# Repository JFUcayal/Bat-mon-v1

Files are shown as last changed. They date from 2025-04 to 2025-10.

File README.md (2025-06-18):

# Bat-mon-v1
**Edge Device for Battery Environment Monitoring System (Lithium Storage and Transport)**

- **Bat-Mon** is a hardware/firmware project developed as part of my Master's thesis in an industrial environment at [b.again](https://b.again.pt/pt_PT/) [(dstgroup)](https://www.dstsgps.com/intro-pt-pt/#/#intro), focused on the real-time monitoring of lithium batteries. 
- It includes custom-designed PCBs for fixed and portable use cases, enabling the detection of environmental conditions such as **temperature**, **humidity**, and **vibration**. All hardware was developed using **KiCAD**.
- This project was developed in the context of a national R&D consortium for advanced energy storage systems:  
[New Generation Storage](https://newgenstorage.pt). It is partially funded by the **PRR – Recovery and Resilience Plan** and aims to support innovation in battery safety and smart monitoring systems.

## 🔧 Project Overview

Lithium batteries, whether in stationary storage or during transport, require careful environmental monitoring to ensure safety. Bat-Mon addresses this need by providing two types of monitoring devices:

- **Stationary Unit**: Designed for static storage. Measures temperature and humidity.
- **Portable Unit**: Designed for battery transport scenarios. Measures temperature, humidity, and vibration.

Both units support low-power operation and are intended to be integrated into broader telemetry or management systems.

## 📟 3D Views of the PCBs
<div id="image-table" align="center">
    <table>
        <tr>
            <td style="padding:10px"> <strong>📦 Stationary Monitoring Prototype</strong><br/><br/>
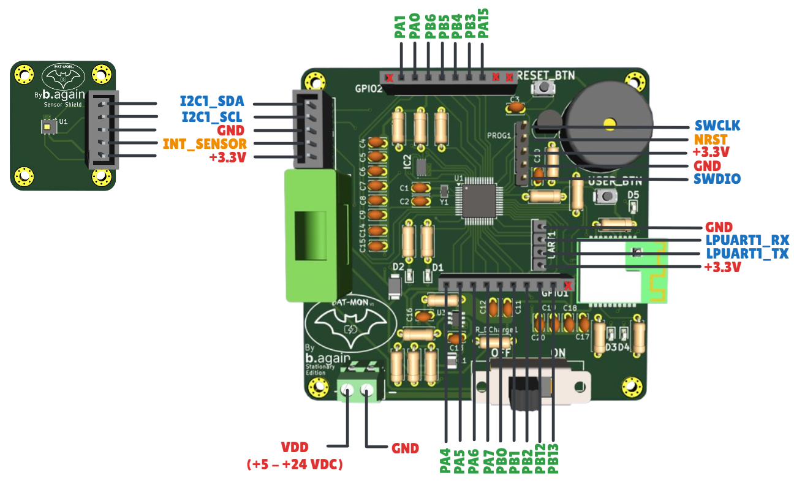
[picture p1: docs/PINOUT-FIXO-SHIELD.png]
Stationary Prototype 3D View
                
            </td>
            <td style="padding:10px"> <br/><strong>🚚 Portable Monitoring Prototype</strong><br/><br/>
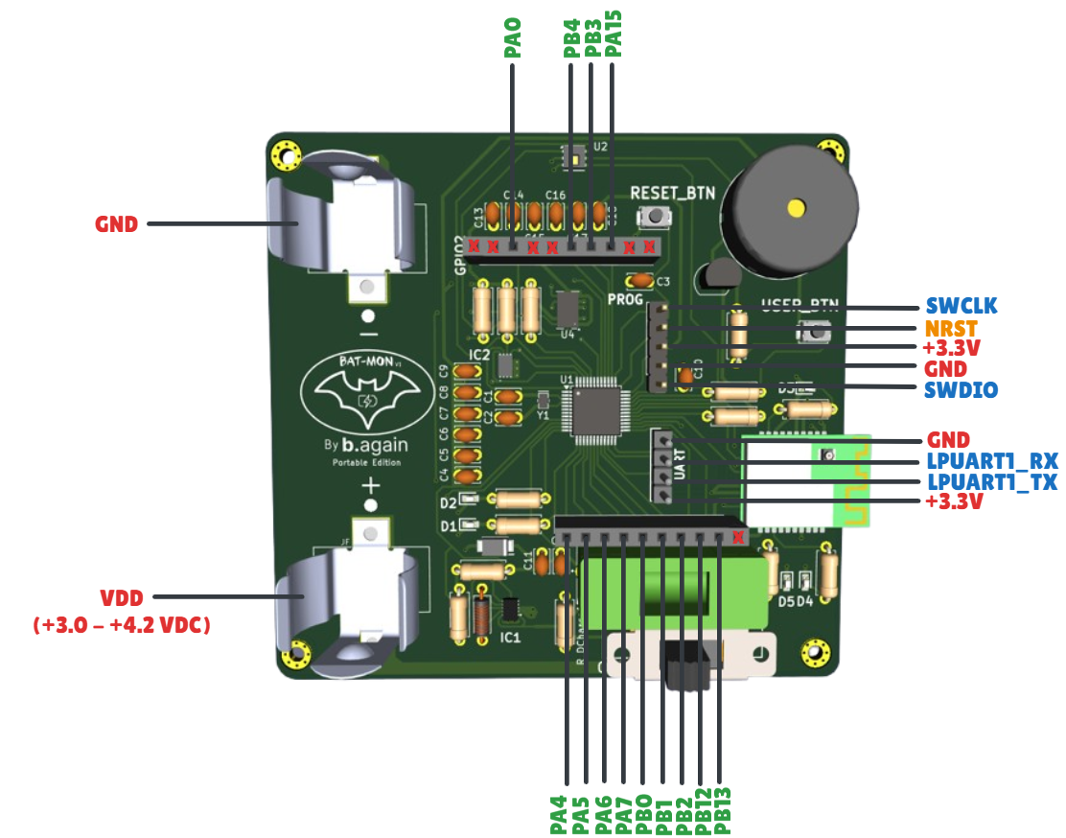
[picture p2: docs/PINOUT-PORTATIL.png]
Portable Prototype 3D View
                 
            </td>
        </tr>
    </table>
</div>
    
## 🚀 Key Features

- 🌡️ **Temperature and Humidity Sensing**
- 📈 **Vibration Detection** (portable unit)
- 📶 **BLE Communication Support**
- 🔋 **Low Power Design**
- 📐 **Designed in KiCAD**
- 🧠 **Powered by STM32**

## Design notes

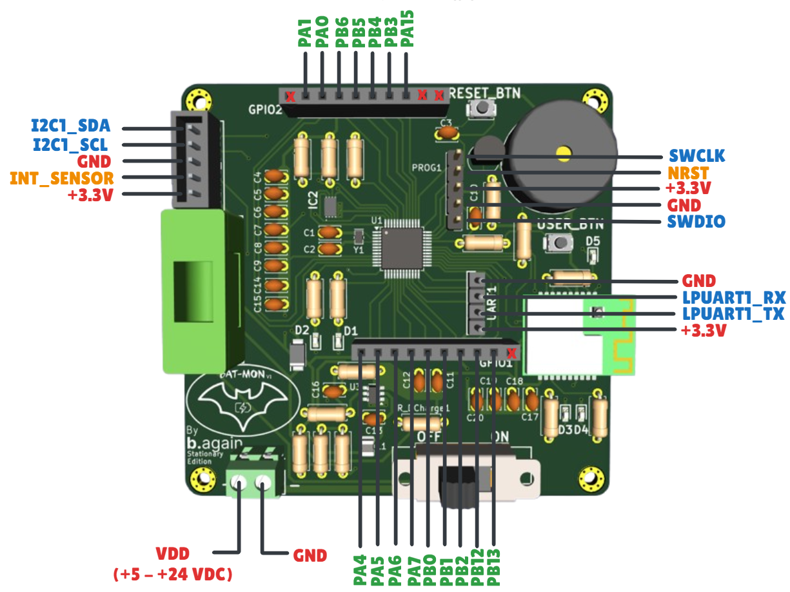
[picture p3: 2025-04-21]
docs/PINOUT-FIXO.png

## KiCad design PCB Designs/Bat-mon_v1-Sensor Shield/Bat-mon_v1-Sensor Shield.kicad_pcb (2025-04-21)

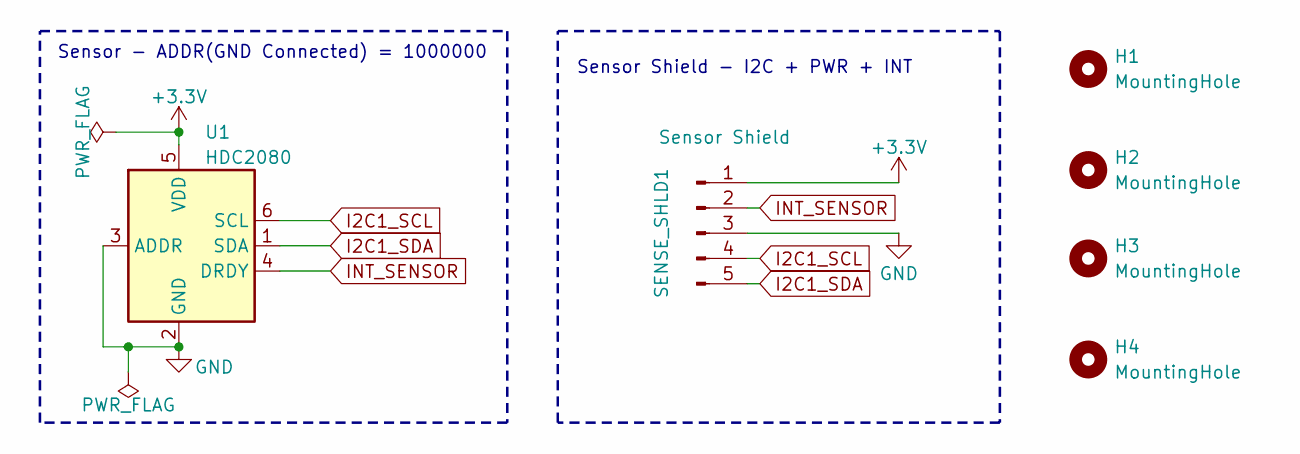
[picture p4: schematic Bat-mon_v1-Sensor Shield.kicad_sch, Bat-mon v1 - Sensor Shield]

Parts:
H1, H2, H3, H4: MountingHole; MountingHole_2.2mm_M2_Pad_Via
SENSE_SHLD1: Sensor Shield; SHDR5W64P0X250_1X5_1490X575X700P
U1: HDC2080; Texas_PWSON-N6

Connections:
+3.3V: SENSE_SHLD1.1, U1.5 (VDD)
GND: SENSE_SHLD1.3, U1.2 (GND), U1.3 (ADDR)
I2C1_SCL: SENSE_SHLD1.4, U1.6 (SCL)
I2C1_SDA: SENSE_SHLD1.5, U1.1 (SDA)
INT_SENSOR: SENSE_SHLD1.2, U1.4 (DRDY)

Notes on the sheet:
Sensor - ADDR(GND Connected) = 1000000
Sensor Shield - I2C + PWR + INT

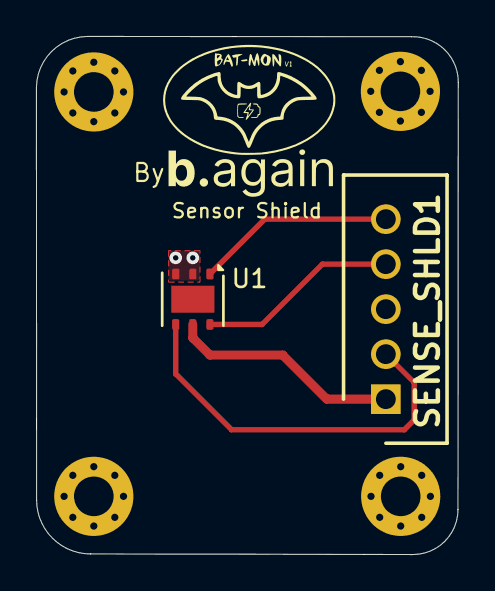
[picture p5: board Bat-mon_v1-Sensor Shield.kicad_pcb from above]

Board: 2 copper layers, 23.4 x 28.8 mm, 6 parts (0 on the bottom side), 5 nets.

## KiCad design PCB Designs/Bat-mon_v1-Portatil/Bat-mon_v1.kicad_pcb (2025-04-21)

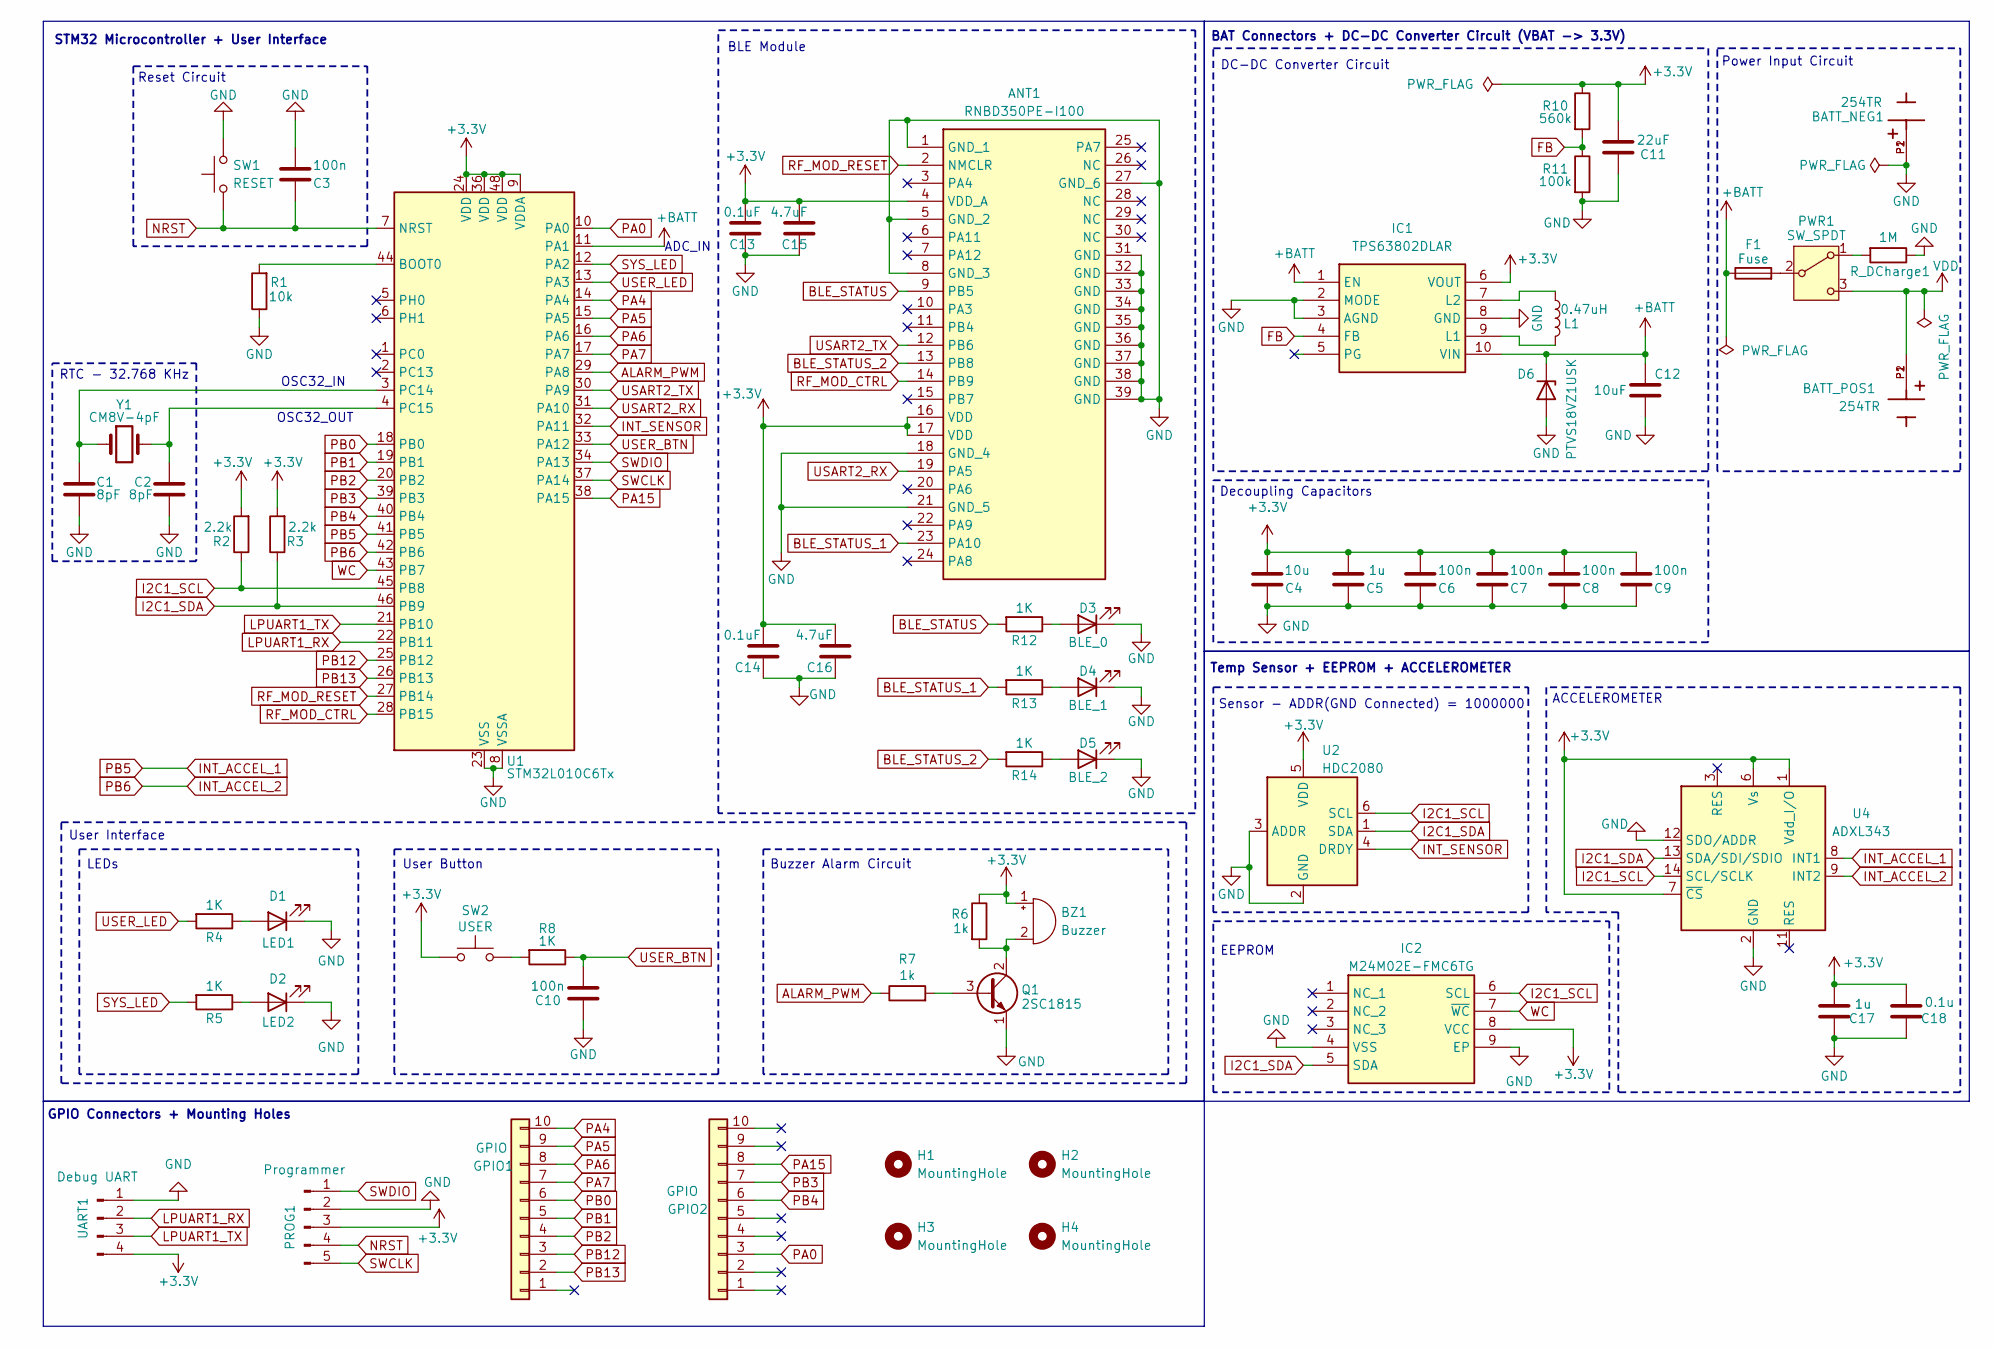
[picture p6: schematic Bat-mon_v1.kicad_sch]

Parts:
ANT1: RNBD350PE-I100; RNBD350PE-I100 - BLE Module; Manufacturer_Part_Number RNBD451PE-I100; Mouser Part Number 579-RNBD451PE-I100
BATT_NEG1: 254TR; BAT_254TR; PARTREV C
BATT_POS1: 254TR; BAT_254TR; PARTREV C
BZ1: Buzzer; PS17_1
C1, C2: 8pF; C_Disc_D3.4mm_W2.1mm_P2.50mm
C3, C6, C7, C8, C9, C10: 100n; C_Disc_D3.4mm_W2.1mm_P2.50mm
C4: 10u; C_Disc_D3.4mm_W2.1mm_P2.50mm
C5, C17: 1u; C_Disc_D3.4mm_W2.1mm_P2.50mm
C11: 22uF; C_Disc_D3.4mm_W2.1mm_P2.50mm
C12: 10uF; C_Disc_D3.4mm_W2.1mm_P2.50mm
C13, C14: 0.1uF; C_Disc_D3.4mm_W2.1mm_P2.50mm
C15, C16: 4.7uF; C_Disc_D3.4mm_W2.1mm_P2.50mm
C18: 0.1u; C_Disc_D3.4mm_W2.1mm_P2.50mm
D1: LED1; LEDC1608X80N
D2: LED2; LEDC1608X80N
D3: BLE_0; LEDC1608X80N
D4: BLE_1; LEDC1608X80N
D5: BLE_2; LEDC1608X80N
D6: PTVS18VZ1USK; SODFL4725X105N
F1: Fuse; WR-FSH_THT_2
GPIO1, GPIO2: GPIO; Header_F_1X10_61301011821
H1, H2, H3, H4: MountingHole; MountingHole_2.2mm_M2_Pad_Via
IC1: TPS63802DLAR; Mouser Part Number 595-TPS63802DLAR
IC2: M24M02E-FMC6TG; M24M02EFMC6TG; Mouser Part Number 511-M24M02E-FMC6TG
L1: 0.47uH; L_Axial_L5.3mm_D2.2mm_P7.62mm_Horizontal_Vishay_IM-1
PROG1: Programmer; PinHeader_1x05_P2.54mm_Vertical
PWR1: SW_SPDT; SLW2327758AND
Q1: 2SC1815; TO-92_Inline
R1: 10k; R_Axial_DIN0207_L6.3mm_D2.5mm_P7.62mm_Horizontal
R2, R3: 2.2k; R_Axial_DIN0207_L6.3mm_D2.5mm_P7.62mm_Horizontal
R4, R5, R8, R12, R13, R14: 1K; R_Axial_DIN0207_L6.3mm_D2.5mm_P7.62mm_Horizontal
R6, R7: 1k; R_Axial_DIN0207_L6.3mm_D2.5mm_P7.62mm_Horizontal
R10: 560k; R_Axial_DIN0207_L6.3mm_D2.5mm_P7.62mm_Horizontal
R11: 100k; R_Axial_DIN0207_L6.3mm_D2.5mm_P7.62mm_Horizontal
R_DCharge1: 1M; R_Axial_DIN0207_L6.3mm_D2.5mm_P7.62mm_Horizontal
SW1: RESET; SW_Push_SPST_NO_Alps_SKRK
SW2: USER; SW_Push_SPST_NO_Alps_SKRK
U1: STM32L010C6Tx; LQFP-48_7x7mm_P0.5mm
U2: HDC2080; Texas_PWSON-N6
U4: ADXL343; LGA-14_3x5mm_P0.8mm_LayoutBorder1x6y
UART1: Debug UART; Header_M_1X4_61300411121
Y1: CM8V-4pF; Crystal_SMD_MicroCrystal_CC8V-T1A-2Pin_2.0x1.2mm

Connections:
+3.3V: ANT1.4 (VDD_A), ANT1.16 (VDD), ANT1.17 (VDD), BZ1.1 (+), C4.2, C5.2, C6.2, C7.2, C8.2, C9.2, C11.2, C13.2, C14.2, C15.2, C16.2, C17.2, C18.2, IC1.6 (VOUT), IC2.8 (VCC), PROG1.3, R2.2, R3.2, R6.1, R10.1, SW2.1, U1.9 (VDDA), U1.24 (VDD), U1.36 (VDD), U1.48 (VDD), U2.5 (VDD), U4.1 (Vdd_I/O), U4.6 (Vs), U4.7 (~CS), UART1.4
+BATT: C12.2, D6.1 (K), F1.1, IC1.1 (EN), IC1.10 (VIN), U1.11 (PA1)
ALARM_PWM: R7.1, U1.29 (PA8)
BLE_STATUS: ANT1.9 (PB5), R12.2
BLE_STATUS_1: ANT1.23 (PA10), R13.2
BLE_STATUS_2: ANT1.13 (PB8), R14.2
FB: IC1.4 (FB), R10.2, R11.1
GND: ANT1.1 (GND_1), ANT1.5 (GND_2), ANT1.8 (GND_3), ANT1.18 (GND_4), ANT1.21 (GND_5), ANT1.27 (GND_6), ANT1.31 (GND), ANT1.32 (GND), ANT1.33 (GND), ANT1.34 (GND), ANT1.35 (GND), ANT1.36 (GND), ANT1.37 (GND), ANT1.38 (GND), ANT1.39 (GND), BATT_NEG1.P1, BATT_NEG1.P2, C1.2, C2.2, C3.2, C4.1, C5.1, C6.1, C7.1, C8.1, C9.1, C10.1, C11.1, C12.1, C13.1, C14.1, C15.1, C16.1, C17.1, C18.1, D1.1 (K), D2.1 (K), D3.1 (K), D4.1 (K), D5.1 (K), D6.2 (A), IC1.2 (MODE), IC1.3 (AGND), IC1.8 (GND), IC2.4 (VSS), IC2.9 (EP), PROG1.2, Q1.1 (E), R1.1, R11.2, R_DCharge1.1, SW1.2, U1.8 (VSSA), U1.23 (VSS), U1.35 (VSS), U1.47 (VSS), U2.2 (GND), U2.3 (ADDR), U4.2 (GND), U4.4 (GND), U4.5 (GND), U4.12 (SDO/ADDR), UART1.1
I2C1_SCL: IC2.6 (SCL), R2.1, U1.45 (PB8), U2.6 (SCL), U4.14 (SCL/SCLK)
I2C1_SDA: IC2.5 (SDA), R3.1, U1.46 (PB9), U2.1 (SDA), U4.13 (SDA/SDI/SDIO)
INT_ACCEL_1: U1.41 (PB5), U4.8 (INT1)
INT_ACCEL_2: U1.42 (PB6), U4.9 (INT2)
INT_SENSOR: U1.32 (PA11), U2.4 (DRDY)
LPUART1_RX: U1.22 (PB11), UART1.2
LPUART1_TX: U1.21 (PB10), UART1.3
NRST: C3.1, PROG1.4, SW1.1, U1.7 (NRST)
unnamed: BZ1.2 (-), Q1.2 (C), R6.2
unnamed: D1.2 (A), R4.1
unnamed: D2.2 (A), R5.1
unnamed: D3.2 (A), R12.1
unnamed: D4.2 (A), R13.1
unnamed: D5.2 (A), R14.1
unnamed: IC1.9 (L1), L1.2
unnamed: IC1.7 (L2), L1.1
unnamed: PWR1.1 (A), R_DCharge1.2
unnamed: F1.2, PWR1.2 (B)
unnamed: Q1.3 (B), R7.2
unnamed: R8.2, SW2.2
unnamed: R1.2, U1.44 (BOOT0)
unnamed: C1.1, U1.3 (PC14), Y1.1
unnamed: C2.1, U1.4 (PC15), Y1.2
PA0: GPIO2.3, U1.10 (PA0)
PA4: GPIO1.10, U1.14 (PA4)
PA5: GPIO1.9, U1.15 (PA5)
PA6: GPIO1.8, U1.16 (PA6)
PA7: GPIO1.7, U1.17 (PA7)
PA15: GPIO2.8, U1.38 (PA15)
PB0: GPIO1.6, U1.18 (PB0)
PB1: GPIO1.5, U1.19 (PB1)
PB2: GPIO1.4, U1.20 (PB2)
PB3: GPIO2.7, U1.39 (PB3)
PB4: GPIO2.6, U1.40 (PB4)
PB12: GPIO1.3, U1.25 (PB12)
PB13: GPIO1.2, U1.26 (PB13)
RF_MOD_CTRL: ANT1.14 (PB9), U1.28 (PB15)
RF_MOD_RESET: ANT1.2 (NMCLR), U1.27 (PB14)
SWCLK: PROG1.5, U1.37 (PA14)
SWDIO: PROG1.1, U1.34 (PA13)
SYS_LED: R5.2, U1.12 (PA2)
USART2_RX: ANT1.19 (PA5), U1.31 (PA10)
USART2_TX: ANT1.12 (PB6), U1.30 (PA9)
USER_BTN: C10.2, R8.1, U1.33 (PA12)
USER_LED: R4.2, U1.13 (PA3)
VDD: BATT_POS1.P1, BATT_POS1.P2, PWR1.3 (C)
WC: IC2.7 (~WC), U1.43 (PB7)

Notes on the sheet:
EEPROM
GPIO Connectors + Mounting Holes
BLE Module
User Button
RTC - 32.768 KHz
User Interface
LEDs
BAT Connectors + DC-DC Converter Circuit (VBAT -> 3.3V)
Sensor - ADDR(GND Connected) = 1000000
DC-DC Converter Circuit
STM32 Microcontroller + User Interface
OSC32_IN
Temp Sensor + EEPROM + ACCELEROMETER
OSC32_OUT
ADC_IN
Buzzer Alarm Circuit
Decoupling Capacitors
Power Input Circuit
ACCELEROMETER
Reset Circuit

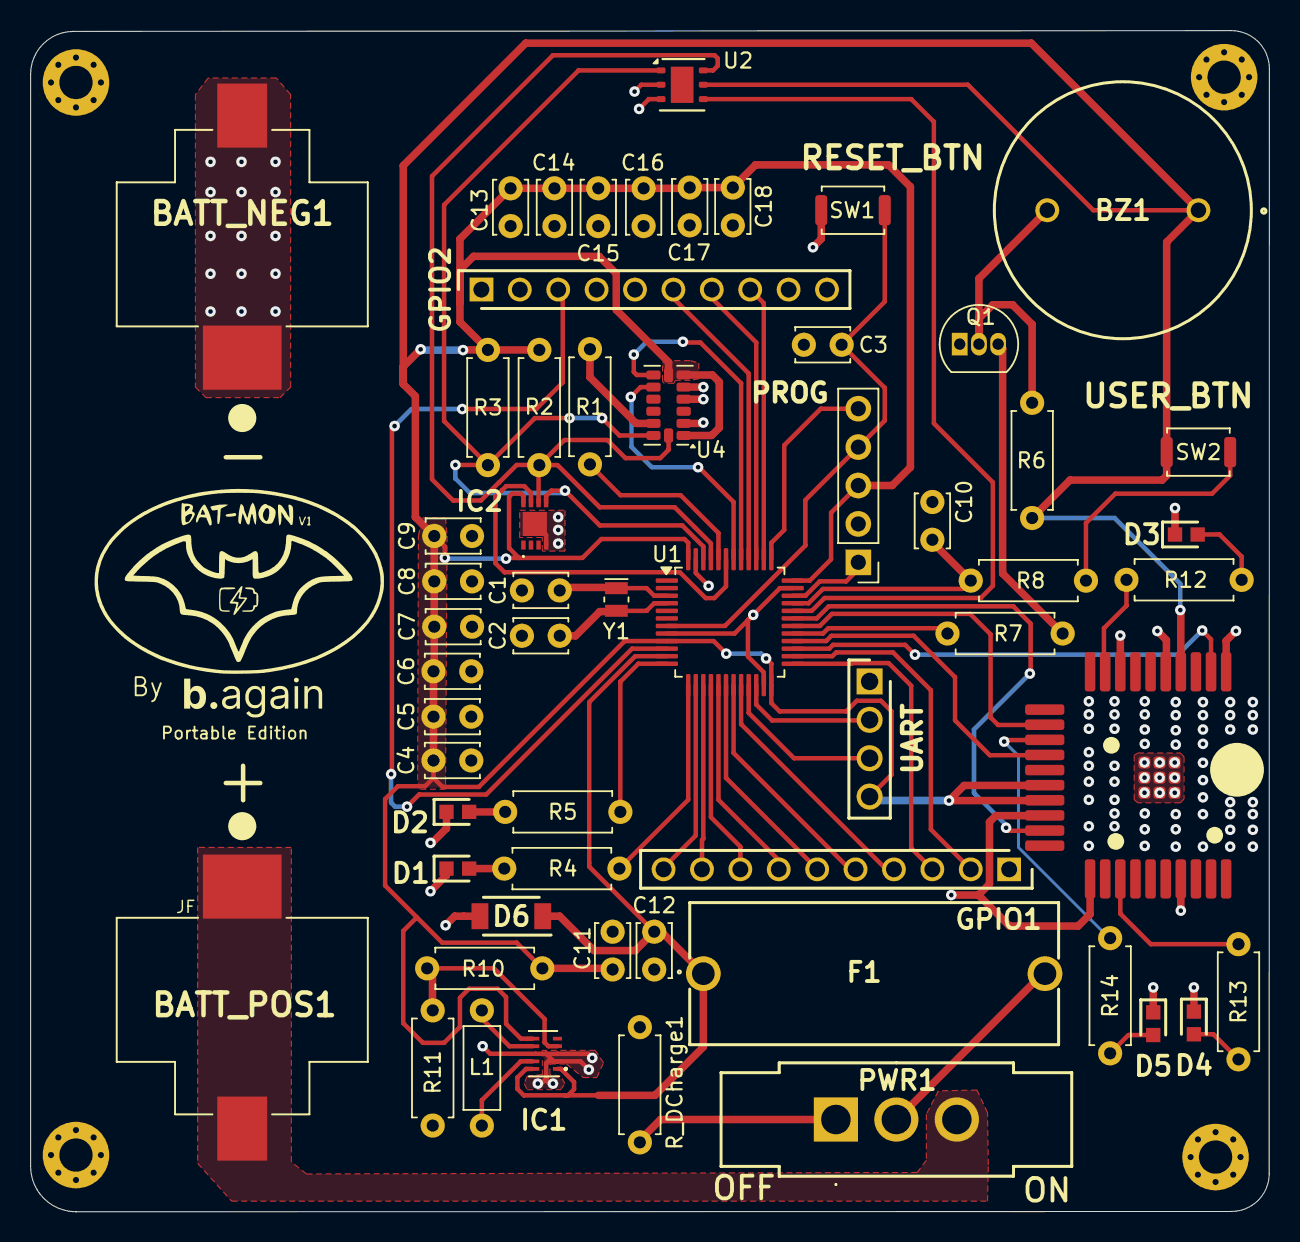
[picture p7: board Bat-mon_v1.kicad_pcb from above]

Board: 2 copper layers, 81.9 x 78.1 mm, 62 parts (0 on the bottom side), 55 nets.

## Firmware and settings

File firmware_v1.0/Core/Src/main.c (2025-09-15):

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
/* Includes ------------------------------------------------------------------*/
#include "main.h"
#include "i2c.h"
#include "usart.h"
#include "rtc.h"
#include "tim.h"
#include "gpio.h"

/* USER CODE BEGIN Includes */
#include <stdio.h>
#include "app.h"
/* USER CODE END Includes */


/* USER CODE BEGIN PV */
uint8_t volatile button_counter = 0;
uint32_t current_millisecs = 0, last_debounce_time = 0;
bool flag_timer_on = false;
extern enum states NEXT_STATE;
/* USER CODE END PV */

void SystemClock_Config(void);
/* USER CODE BEGIN 0 */

void HAL_GPIO_EXTI_Callback(uint16_t GPIO_Pin){

	// Check USER BUTTON click number (Manual Mode)
	if(GPIO_Pin == USER_BTN){


		// blink sys LED
		//HAL_GPIO_TogglePin(GPIOA, SYS_LED_PIN);


		//Debounce
		current_millisecs = HAL_GetTick();
		if(current_millisecs >= 0xFFFFFFF0){
			current_millisecs  = 0;
			last_debounce_time = 0;
		}

		// Check condition for debounce time
		if(current_millisecs - last_debounce_time >= DEBOUNCE_DELAY){

			//log_write(WARNING_LOG, "INT BUTTON ");

			if(!flag_timer_on){
				flag_timer_on = true;
				// stop_timer -> stop time trigger and start counting button time trigger
				start_timer_INT(BUTTON_TIMER);
			}
			button_counter++;
		}
		//For checking the difference between this interrupt and the upcoming INT
		last_debounce_time = current_millisecs;


		// blink sys LED
		//HAL_GPIO_TogglePin(GPIOA, SYS_LED_PIN);
	}

	// Check T+H Sensor INT source
	if(GPIO_Pin == INT_HDC2080_PIN){

		//TODO: Testing purpose only
		//log_write(WARNING_LOG, "INT SENSOR GENERATED");

		// Disable T+H Sensor INT -> Re-Enable in IDLE State -> 5 PULSES GENERATED IN EACH INTERRUPT -> clear flag after first INT

		// Check Thresholds bits (Temp High || Hum High)
		if(check_threshold_active()){
			NEXT_STATE = ANOMALY;
		} else {
			NEXT_STATE = IDLE;
		}
	}
}

// TIMER CALLBACK
// De 1 em 1 segundos checkar o valor do button counter e apos avaliar fazer reset
void HAL_TIM_PeriodElapsedCallback(TIM_HandleTypeDef *htim){

	if(htim == BUTTON_TIMER){

		// verificar se flag_button_INT ou flag_time_trigger_INT (sampling time)	TODO: ADD functionality

		flag_timer_on = false;
		stop_timer(BUTTON_TIMER);

		//log_write(WARNING_LOG, "INT time - %u", button_counter);

		switch(button_counter){
			case 1:
				NEXT_STATE = DATA_READ;
				break;
			case 2:
				NEXT_STATE = LOGS;
				break;
			case 3:
				NEXT_STATE = RECONNECT;
				break;
			case 5:
				NEXT_STATE = CLEAN_MEM;
				break;
			default:
				//log_write(WARNING_LOG, "Redirecting to IDLE...");
				NEXT_STATE = IDLE;
				break;
		}
		button_counter = 0;
	}
}
/* USER CODE END 0 */

/**
  * @brief  The application entry point.
  * @retval int
  */
int main(void)
{

  /* MCU Configuration--------------------------------------------------------*/

  /* Reset of all peripherals, Initializes the Flash interface and the Systick. */
  HAL_Init();

  /* Configure the system clock */
  SystemClock_Config();

  /* Initialize all configured peripherals */
  MX_GPIO_Init();
  MX_I2C1_Init();
  MX_LPUART1_UART_Init();
  MX_RTC_Init();
  MX_TIM21_Init();
  /* USER CODE BEGIN 2 */

  init_device();

  log_write(INFO_LOG, "------------ BAT-MON v1 startup ------------");


  /* USER CODE END 2 */

  /* Infinite loop */
  /* USER CODE BEGIN WHILE */
  while (1)
  {
    /* USER CODE END WHILE */

    /* USER CODE BEGIN 3 */
	  HAL_GPIO_TogglePin(GPIOA, USER_LED_PIN);	//heartbeat
	  HAL_Delay(300);
	  HAL_GPIO_TogglePin(GPIOA, USER_LED_PIN);	//heartbeat
	  app_fsm();
	  HAL_Delay(APP_DELAY);


  }
  /* USER CODE END 3 */
}

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


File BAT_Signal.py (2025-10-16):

import re
import matplotlib.pyplot as plt
import matplotlib.animation as animation
from collections import deque
from datetime import datetime
import threading
import queue
import time

try:
    import serial
    SERIAL_AVAILABLE = True
except ImportError:
    print("pyserial não instalado. Use: pip install pyserial")
    SERIAL_AVAILABLE = False

class BatSignalMonitor:
    def __init__(self, port='COM3', baudrate=115200, max_points=50):
        self.max_points = max_points
        self.data_queue = queue.Queue()
        self.serial_running = True
        self.start_time = None
        self.monitoring_started = False
        self.current_cycle_data = {}  # Armazena todos os dados do ciclo atual
        self.awaiting_cycle_completion = False
        
        # Arrays para dados (apenas inteiros)
        self.timestamps = deque(maxlen=max_points)
        self.seconds = deque(maxlen=max_points)
        self.temperature = deque(maxlen=max_points)
        self.humidity = deque(maxlen=max_points)
        self.accel_x = deque(maxlen=max_points)
        self.accel_y = deque(maxlen=max_points)
        self.accel_z = deque(maxlen=max_points)
        
        # Configurar tema dark moderno
        self.setup_dark_theme()
        self.setup_plots()
        self.ser = self.connect_serial(port, baudrate)
        
    def setup_dark_theme(self):
        """Configura o tema dark moderno"""
        plt.style.use('dark_background')
        self.colors = {
            'background': '#0d1117',
            'card': '#161b22',
            'accent': '#58a6ff',
            'success': '#3fb950',
            'warning': '#d29922',
            'danger': '#f85149',
            'text_primary': '#f0f6fc',
            'text_secondary': '#8b949e',
            'grid': '#30363d',
            'temp': '#ff7b72',
            'humidity': '#79c0ff',
            'accel_x': '#7ee787',
            'accel_y': '#ffa657',
            'accel_z': '#d2a8ff',
        }
        
    def connect_serial(self, port, baudrate):
        """Conecta à porta serial da STM32"""
        if not SERIAL_AVAILABLE:
            print("pyserial não disponível.")
            return None
            
        try:
            ser = serial.Serial(
                port=port,
                baudrate=baudrate,
                timeout=1,
                bytesize=serial.EIGHTBITS,
                parity=serial.PARITY_NONE,
                stopbits=serial.STOPBITS_ONE
            )
            print(f"Conectado à {port} - {baudrate} bps")
            print("Aguardando dados da STM32...")
            return ser
        except Exception as e:
            print(f"Erro ao conectar à {port}: {e}")
            print("Soluções:")
            print("1. Feche o PuTTY e outras apps usando COM3")
            print("2. Verifique se a porta está correta")
            print("3. Execute como Administrador")
            return None
    
    def parse_stm32_line(self, line):
        """Extrai dados da linha da STM32"""
        try:
            # Verifica se é o primeiro READ SENSORS
            if 'Current State -> 1 - READ SENSORS' in line and not self.monitoring_started:
                self.start_time = datetime.now()
                self.monitoring_started = True
                self.awaiting_cycle_completion = True
                self.current_cycle_data = {}  # Inicia novo ciclo
                return {'state': 'start_monitoring'}
            
            # Se é um novo ciclo de READ SENSORS
            if 'Current State -> 1 - READ SENSORS' in line:
                self.awaiting_cycle_completion = True
                self.current_cycle_data = {}  # Inicia novo ciclo
                return None
            
            # Temperatura
            temp_match = re.search(r'Temperature ---->\s*(-?\d+)\s*C', line)
            if temp_match:
                self.current_cycle_data['temperature'] = int(temp_match.group(1))
                return None
            
            # Humidade
            hum_match = re.search(r'Humidity ------->\s*(-?\d+)\s*%', line)
            if hum_match:
                self.current_cycle_data['humidity'] = int(hum_match.group(1))
                return None
            
            # Acelerações
            accel_x_match = re.search(r'X Acceleration ->\s*(-?\d+)\s*mg', line)
            if accel_x_match:
                self.current_cycle_data['accel_x'] = int(accel_x_match.group(1)) 
                return None
            
            accel_y_match = re.search(r'Y Acceleration ->\s*(-?\d+)\s*mg', line)
            if accel_y_match:
                self.current_cycle_data['accel_y'] = int(accel_y_match.group(1)) 
                return None
            
            accel_z_match = re.search(r'Z Acceleration ->\s*(-?\d+)\s*mg', line)
            if accel_z_match:
                self.current_cycle_data['accel_z'] = int(accel_z_match.group(1)) 
                return None
            
            # Se chegou ao COMMS, o ciclo está completo
            if 'Current State -> 2 - COMMS' in line and self.awaiting_cycle_completion:
                if self.current_cycle_data:  # Se temos dados do ciclo
                    self.current_cycle_data['timestamp'] = datetime.now()
                    self.awaiting_cycle_completion = False
                    return self.current_cycle_data.copy()  # Envia ponto completo
            
            return None
            
        except Exception as e:
            print(f"Erro no parse: {e} - Linha: {line}")
            return None
    
    def read_serial_data(self):
        """Lê dados da STM32 LINHA A LINHA"""
        if not self.ser:
            print("Porta serial não disponível.")
            return
            
        buffer = ""
        while self.serial_running:
            try:
                if self.ser and self.ser.in_waiting:
                    # Lê dados disponíveis
                    data = self.ser.read(self.ser.in_waiting).decode('utf-8', errors='ignore')
                    buffer += data
                    
                    # Processa CADA LINHA individualmente
                    while '\n' in buffer:
                        line, buffer = buffer.split('\n', 1)
                        line = line.strip()
                        
                        if line:
                            print(f"Linha recebida: {line}")
                            parsed_data = self.parse_stm32_line(line)
                            if parsed_data:
                                # Envia APENAS UM PONTO COMPLETO por ciclo
                                self.data_queue.put(parsed_data)
                                print(f"✅ Ponto completo preparado: {parsed_data}")
                                
            except Exception as e:
                print(f"Erro serial: {e}")
                time.sleep(1)
    
    def setup_plots(self):
        """Configura os 3 gráficos com design moderno e dark"""
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

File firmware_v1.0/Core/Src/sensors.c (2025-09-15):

/*
 * sensors.c
 *
 *  Created on: Jun 17, 2025
 *      Author: dst2001055
 */

#include "sensors.h"

// HDC2080
uint8_t  sensor_data[4];
uint16_t temp_value;
uint16_t hum_value;

// ADXL343
int16_t raw_acceleration[3];

// -----------------------------------------------------------------	HDC2080 - T/H Sensor	----------------------------------------------------------------------

uint8_t config_T_H_sensor(uint8_t temp_max, uint8_t hum_max){

	uint8_t config_command[2];

	config_command[0] = 0x0E;
	config_command[1] = 0x80;

	write_i2c_sensor(HDC2080_ADDR, config_command, sizeof(config_command));


	// Set thresholds of TEMP & HUM for INTERRUPT
	set_thresholds_T_H(temp_max, hum_max);


	// INT Config (0x07):  7	   6      5      4	    3		2 1 0
	// 				     DRY_EN  TH_EN  TL_EN  HH_EN  HL_EN 	 RES
	// TRIGG		       0       1      0      1      0       0 0 0 -> 0x50

	config_command[0] = 0x07;
	config_command[1] = 0x50;

	//config_command[1] = 0x80;

	write_i2c_sensor(HDC2080_ADDR, config_command, sizeof(config_command));

	// RESET + DRDY Config (0x0E):  7	6  5  4	     3		  2		     1		 0
	// 				 			  S_RST AMM[6:4]  HEAT_EN DDRY/INT_EN INT_POL INT_MODE
	// TRIGG		   				0   0  1  1      0        1          1       0 -> 0x36

	config_command[0] = 0x0E;
	config_command[1] = 0x36;

	write_i2c_sensor(HDC2080_ADDR, config_command, sizeof(config_command));


	// Measure (0x0F): 7	 6	  5	    4	3	2	         1	     0
	// 				  TRES[7:6]  HRES[5:4]  x  MEAS_CONFIG[2:1]  MEAS_TRIG
	// TRIGG		   0     0	  0     0   0   0            0      0/1  -> 0x00/0x01

	config_command[0] = 0x0F;
	config_command[1] = 0X00;

	write_i2c_sensor(HDC2080_ADDR, config_command, sizeof(config_command));

	// 1st HDC2080 measure
	sample_temp_hum();

	return NO_ERROR;
}


uint8_t sample_temp_hum(){

	uint8_t  measure_command[2];
	uint8_t  reading_command[1];

	// Send measure command
	measure_command[0] = 0x0F;
	measure_command[1] = 0X01;

	write_i2c_sensor(HDC2080_ADDR, measure_command, sizeof(measure_command));

	wait_delay(SENSOR_DELAY_MS);

	// Read data registers
	reading_command[0] = 0x00;
	write_i2c_sensor(HDC2080_ADDR, reading_command, sizeof(reading_command));
	read_i2c_sensor(HDC2080_ADDR, sensor_data, sizeof(sensor_data));

	return NO_ERROR;
}


float get_temperature(){

	float temp_value_float;

	temp_value = (sensor_data[TEMP_HIGH] << 8 | sensor_data[TEMP_LOW]);
	temp_value_float = temp_value;

	temp_value_float = ((temp_value_float * 165.0f) / 65536.0f) - (40.5f + 0.08f * (3.3f - 1.8f));

	return temp_value_float;
}


float get_humidity(){

	float hum_value_float;

	hum_value = (sensor_data[HUM_HIGH] << 8 | sensor_data[HUM_LOW]);

	hum_value_float = hum_value;
	hum_value_float = (hum_value_float / 65536.0f) * 100.0f;

	return hum_value_float;
}


uint8_t set_thresholds_T_H(uint8_t temp_max, uint8_t hum_max){

	uint8_t temp_high, hum_high;
	uint8_t configh_TRSHLD_command[2];

//----------------------------------- TEMPERATURE ------------------------------------------

	if(temp_max >= TEMP_MAX_LIMIT){
		temp_max = TEMP_MAX_LIMIT;
	}
	else if(temp_max <= TEMP_MIN_LIMIT){
		temp_max = TEMP_MIN_LIMIT;
	}

	temp_high = (uint8_t)(256.0f * (temp_max + 40.0f) / 165.0f);

	configh_TRSHLD_command[0] = 0x0B;
	configh_TRSHLD_command[1] = temp_high;

	write_i2c_sensor(HDC2080_ADDR, configh_TRSHLD_command, sizeof(configh_TRSHLD_command));

//----------------------------------- HUMIDITY ------------------------------------------

	if(hum_max >= HUM_MAX_LIMIT){
		hum_max = HUM_MAX_LIMIT;
	}
	else if(hum_max <= HUM_MIN_LIMIT){
		hum_max = HUM_MIN_LIMIT;
	}

	hum_high = (uint8_t)(256.0f * hum_max / 100.0f);

	configh_TRSHLD_command[0] = 0x0D;
	configh_TRSHLD_command[1] = hum_high;

	write_i2c_sensor(HDC2080_ADDR, configh_TRSHLD_command, sizeof(configh_TRSHLD_command));

	return NO_ERROR;
}

// -----------------------------------------------------------------	ADXL343 - ACCELEROMETER		----------------------------------------------------------------------

uint8_t config_ACCEL_sensor(){

	uint8_t reading_command[1];
	uint8_t config_command[2];

	// Reading device ID
	reading_command[0] = 0x00;

	write_i2c_sensor(ADXL343_ADDR, reading_command, sizeof(reading_command));
	read_i2c_sensor(ADXL343_ADDR, sensor_data, sizeof(sensor_data));

	if(sensor_data[0] != 0xE5){
		return CONFIG_SENSOR_ERROR;
	}

	// CONFIG DATA FORMAT
	config_command[0] = 0x31;
	config_command[1] = 0x09;

	write_i2c_sensor(ADXL343_ADDR, config_command, sizeof(config_command));


	// MEASURE MODE
	config_command[0] = 0x2D;
	//config_command[1] = 0x08; //0x38 -> LINK + AUTO_SLEEP + MEASURE
	config_command[1] = 0x18;

	write_i2c_sensor(ADXL343_ADDR, config_command, sizeof(config_command));


	return NO_ERROR;
}

uint8_t sample_accel(){

	uint8_t reading_command[2];
	uint8_t config_command[2];
	uint8_t accel_data[6];


	// MEASURE MODE
	config_command[0] = 0x2D;
	config_command[1] = 0x08;

	write_i2c_sensor(ADXL343_ADDR, config_command, sizeof(config_command));


	// Get X, Y, Z
	reading_command[0] = 0x32;

	write_i2c_sensor(ADXL343_ADDR, reading_command, sizeof(reading_command));
	read_i2c_sensor(ADXL343_ADDR, accel_data, sizeof(accel_data));

	raw_acceleration[0] = (accel_data[1] << 8 | accel_data[0]);
	raw_acceleration[1] = (accel_data[3] << 8 | accel_data[2]);
	raw_acceleration[2] = (accel_data[5] << 8 | accel_data[4]);

	return NO_ERROR;
}


accel_axis get_accel(){

	accel_axis acceleration[SAMPLE_SIZE];
	accel_axis accel_average;

	for(uint8_t i=0; i < SAMPLE_SIZE; i++){

		sample_accel();

		acceleration[i].x_axis_accel = (raw_acceleration[0] * ACCEL_SENSE);
		accel_average.x_axis_accel += acceleration[i].x_axis_accel;

		acceleration[i].y_axis_accel = (raw_acceleration[1] * ACCEL_SENSE);
		accel_average.y_axis_accel += acceleration[i].y_axis_accel;

		acceleration[i].z_axis_accel = (raw_acceleration[2] * ACCEL_SENSE);
		accel_average.z_axis_accel += acceleration[i].z_axis_accel;

		wait_delay(ACCEL_DELAY_MS);
	}


	accel_average.x_axis_accel = (accel_average.x_axis_accel / SAMPLE_SIZE) * ACCEL_MG_FACTOR;
	accel_average.y_axis_accel = (accel_average.y_axis_accel / SAMPLE_SIZE) * ACCEL_MG_FACTOR;
	accel_average.z_axis_accel = (accel_average.z_axis_accel / SAMPLE_SIZE) * ACCEL_MG_FACTOR;


	//PUT ACCEL in sleep mode
	//SLEEP MODE -> bit 2 in 0x2D REGISTER

	return accel_average;
}


// -------------------------------------------------------------------------------------------------------------------------------------------------------------------
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

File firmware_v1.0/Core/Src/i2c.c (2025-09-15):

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
/* Includes ------------------------------------------------------------------*/
#include "i2c.h"

I2C_HandleTypeDef hi2c1;

/* I2C1 init function */
void MX_I2C1_Init(void)
{

  hi2c1.Instance = I2C1;
  hi2c1.Init.Timing = 0x00000202;
  hi2c1.Init.OwnAddress1 = 0;
  hi2c1.Init.AddressingMode = I2C_ADDRESSINGMODE_7BIT;
  hi2c1.Init.DualAddressMode = I2C_DUALADDRESS_DISABLE;
  hi2c1.Init.OwnAddress2 = 0;
  hi2c1.Init.OwnAddress2Masks = I2C_OA2_NOMASK;
  hi2c1.Init.GeneralCallMode = I2C_GENERALCALL_DISABLE;
  hi2c1.Init.NoStretchMode = I2C_NOSTRETCH_DISABLE;
  if (HAL_I2C_Init(&hi2c1) != HAL_OK)
  {
    Error_Handler();
  }

  /** Configure Analogue filter
  */
  if (HAL_I2CEx_ConfigAnalogFilter(&hi2c1, I2C_ANALOGFILTER_ENABLE) != HAL_OK)
  {
    Error_Handler();
  }

  /** Configure Digital filter
  */
  if (HAL_I2CEx_ConfigDigitalFilter(&hi2c1, 0) != HAL_OK)
  {
    Error_Handler();
  }
}

void HAL_I2C_MspInit(I2C_HandleTypeDef* i2cHandle)
{

  GPIO_InitTypeDef GPIO_InitStruct = {0};
  if(i2cHandle->Instance==I2C1)
  {
    __HAL_RCC_GPIOB_CLK_ENABLE();
    /**I2C1 GPIO Configuration
    PB8     ------> I2C1_SCL
    PB9     ------> I2C1_SDA
    */
    GPIO_InitStruct.Pin = GPIO_PIN_8|GPIO_PIN_9;
    GPIO_InitStruct.Mode = GPIO_MODE_AF_OD;
    GPIO_InitStruct.Pull = GPIO_NOPULL;
    GPIO_InitStruct.Speed = GPIO_SPEED_FREQ_VERY_HIGH;
    GPIO_InitStruct.Alternate = GPIO_AF4_I2C1;
    HAL_GPIO_Init(GPIOB, &GPIO_InitStruct);

    /* I2C1 clock enable */
    __HAL_RCC_I2C1_CLK_ENABLE();
  }
}

void HAL_I2C_MspDeInit(I2C_HandleTypeDef* i2cHandle)
{

  if(i2cHandle->Instance==I2C1)
  {
    /* Peripheral clock disable */
    __HAL_RCC_I2C1_CLK_DISABLE();

    /**I2C1 GPIO Configuration
    PB8     ------> I2C1_SCL
    PB9     ------> I2C1_SDA
    */
    HAL_GPIO_DeInit(GPIOB, GPIO_PIN_8);

    HAL_GPIO_DeInit(GPIOB, GPIO_PIN_9);

  }
}

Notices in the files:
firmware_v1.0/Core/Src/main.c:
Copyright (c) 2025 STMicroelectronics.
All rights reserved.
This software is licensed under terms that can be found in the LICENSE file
